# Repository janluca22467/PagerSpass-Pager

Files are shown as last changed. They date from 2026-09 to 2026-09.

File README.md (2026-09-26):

# PagerSpass Pager

Ein echter kleiner Funkmelder zum Selberbauen für **PagerSpass**. Optisch angelehnt an den Swissphone s.QUAD X35.

Du bist in einer Runde am PC, es kommt ein Alarm – und der Melder auf dem Tisch piept, die rote LED blinkt und auf dem Display steht die Meldung. Genau wie im Spiel, nur in echt.

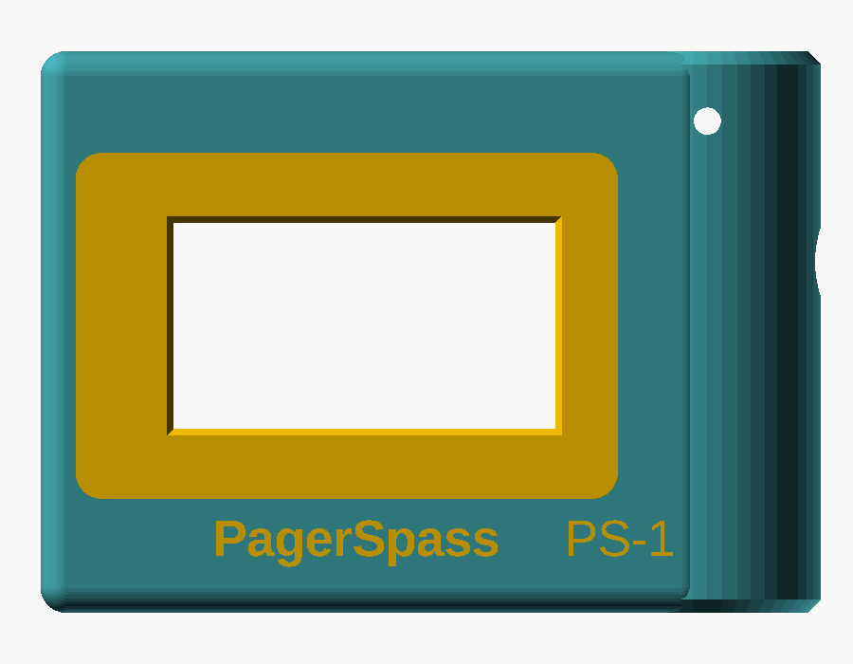
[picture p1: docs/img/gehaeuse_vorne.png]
Gehäuse


## Was kann er?

- Alarmierung mit Ton, roter LED und Anzeige wie im Spiel (Datum, Uhrzeit, Adresse, Text)
- Quittieren per Tastendruck – im Spiel ist der Alarm dann auch quittiert
- Anmeldung mit dem normalen PagerSpass Konto, kein Premium nötig
- Nachrichtenspeicher (die letzten 20)
- Melder-Menü: Lautstärke, Alarmton, Helligkeit, Stumm, Info …
- Einrichtung komplett über das Handy, kein Programmieren nötig
- Akku mit USB-C Laden

## Einrichtung in Kurz

1. Einschalten → „Willkommen zu PagerSpass Pager“
2. Mit dem Handy ins WLAN **Pager-XXXX** gehen, die Einrichtungsseite geht von selbst auf
3. Eigenes WLAN eintragen
4. PagerSpass Benutzername + Passwort eintragen (wie im Spiel)
5. Fertig – der Pager wartet jetzt auf eine Runde

## Teile

WeMos D1 Mini (ESP8266), 1.9" ST7789 Display (170x320), 4 Taster, Mini-Lautsprecher, rote LED, LiPo + TP4056. Zusammen ca. **15–20 €**. Genaue Liste: [docs/TEILELISTE.md](docs/TEILELISTE.md)

## Ordner

| Ordner | Inhalt |
|---|---|
| `firmware/` | Code für den D1 Mini (PlatformIO), dazu ein Simulator-Build |
| `case/` | Gehäuse, OpenSCAD-Datei + fertige STL |
| `hardware/` | Schaltplan |
| `tools/testserver/` | Testserver zum Ausprobieren ohne Spiel |

Braucht PagerSpass mit Pager-Anschluss (`/hub/pager`).
| `docs/` | Anleitung, Bedienung, Protokoll |

## Doku

- [Teileliste](docs/TEILELISTE.md)
- [Bauanleitung](docs/BAUANLEITUNG.md)
- [Bedienung](docs/BEDIENUNG.md)
- [Protokoll (für Server/Spiel)](docs/PROTOKOLL.md)
- [Am Mac testen ohne Hardware (Simulator)](docs/SIMULATOR.md)

## Lizenz

MIT, siehe [LICENSE](LICENSE). Nachbauen, verändern, verbessern – gerne! Pull Requests sind willkommen.

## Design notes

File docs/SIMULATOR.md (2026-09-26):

# Pager am Mac testen (ohne Hardware)

Mit **Wokwi** läuft die echte Firmware im Simulator: Display, Tasten, LED und Piepser sind auf dem Bildschirm, WLAN geht auch.

Unterschiede zum echten Gerät:

- Wokwi kann keinen ESP8266, darum läuft der Simulator auf einem **ESP32**. Der Code ist derselbe, nur die Pins sind andere.
- Wokwi hat kein 1.9" ST7789, darum nimmt der Simulator ein ILI9341 und nutzt davon einen Streifen mit 320x170 Pixeln.

## Einmal einrichten

1. **VS Code** installieren: https://code.visualstudio.com
2. In VS Code bei Erweiterungen installieren:
   - **PlatformIO IDE**
   - **Wokwi Simulator**
3. `F1` → „Wokwi: Request a new License“ → im Browser bestätigen (für Hobby kostenlos)
4. **Python 3** ist auf dem Mac meistens schon da (`python3 --version` im Terminal). Für den Testserver:
   ```
   cd tools/testserver
   pip3 install -r requirements.txt
   ```

## Starten

1. In VS Code **nur den Ordner `firmware/`** öffnen (Datei → Ordner öffnen)
2. Unten in der blauen Leiste bei PlatformIO die Umgebung **`env:sim`** wählen und auf ✓ (Build) klicken
   – oder im Terminal: `pio run -e sim`
3. `diagram.json` öffnen → der Pager wird angezeigt
4. `F1` → **„Wokwi: Start Simulator“**

Der Pager startet, zeigt „Willkommen“ und verbindet sich automatisch mit dem Simulator-WLAN (`Wokwi-GUEST`). Die WLAN-Einrichtung wird im Simulator übersprungen.

## Testen mit dem Testserver (ohne Spiel)

1. Terminal auf dem Mac:
   ```
   cd tools/testserver
   python3 server.py
   ```
2. Im Browser **http://localhost:8180** öffnen → das ist die Einrichtungsseite vom simulierten Pager
3. Benutzername egal, Passwort `test` → „Anmelden“
   (Server ist im Simulator schon auf `http://host.wokwi.internal:8080` gestellt = dein Mac)
4. Im Terminal vom Testserver:
   ```
   /start Stade
   B3 Wohnhausbrand | Hauptstraße 5 | Rauch aus Dachstuhl
   ```
   → Pager piept, LED blinkt, Meldung erscheint

## Testen mit dem echten Spiel

Geht genauso, nur auf der Einrichtungsseite unter „Erweitert“ als Server `https://pagerspass.de` eintragen und mit dem normalen Konto anmelden. Dann im Spiel einer Runde als Fahrzeug beitreten und alarmieren lassen.

(Der Server muss dafür den Pager-Anschluss schon haben, also nach dem Deploy.)

## Tasten

Man kann die Knöpfe anklicken oder die Tastatur nehmen (vorher einmal ins Simulator-Fenster klicken):

| Taste | Knopf |
|---|---|
| Enter | OK |
| Pfeil hoch | HOCH |
| Pfeil runter | RUNTER |
| Esc | ZURÜCK |

## Log

Unten in VS Code im Terminal-Bereich zeigt Wokwi die Ausgabe vom Pager, z. B.:

```
[boot] PagerSpass Pager 1.0.0
[boot] Display gestartet
[wifi] verbinde mit Wokwi-GUEST
[wifi] verbunden, IP 10.13.37.2
[setup] warte auf Anmeldung, Einrichtungsseite ist offen
```

Wenn was nicht geht: diese Zeilen angucken, da steht wo es hängt.

## Probleme

| Problem | Lösung |
|---|---|
| „firmware.bin not found“ | Erst bauen mit `env:sim`, nicht `env:pager` |
| localhost:8180 geht nicht | Simulator läuft? Pager zeigt „PagerSpass verknüpfen“? Ein paar Sekunden warten |
| „Server nicht erreichbar“ beim Testserver | Läuft `python3 server.py`? Server muss `http://host.wokwi.internal:8080` sein |
| Display bleibt schwarz | Nach dem Ändern immer neu bauen (`env:sim`) und den Simulator neu starten. Im Log muss „Display gestartet“ stehen |
| Alles zurücksetzen | Menü → Werkseinstellungen, oder Simulator neu starten und HOCH+RUNTER halten |

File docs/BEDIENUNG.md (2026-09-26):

# Bedienung

## Tasten

```
   [ZURÜCK]  [ HOCH ]  [RUNTER]
 ┌──────────────────────────┬───┐
 │                          │ ● │  ← LED
 │        Display           │   │
 │                          │ ◉ │  ← OK (Seite)
 │                          │   │
 │ PagerSpass        PS-1   │   │
 └──────────────────────────┴───┘
```

| Taste | kurz | lang |
|---|---|---|
| OK (Seite) | Menü / auswählen / Alarm quittieren | in der Nachrichtenliste: alle löschen |
| HOCH / RUNTER | blättern | schnell blättern |
| ZURÜCK | zurück | – |

Wenn das Display aus ist, macht der erste Tastendruck nur das Licht an. Beim Alarm quittiert jede Taste sofort.

## Erster Start

1. **Willkommen** – Einschalten, das Logo kommt.
2. **WLAN** – Auf dem Display steht `Pager-XXXX`. Mit dem Handy in dieses WLAN gehen. Die Einrichtungsseite geht normalerweise von selbst auf, sonst im Browser `http://192.168.4.1` öffnen. WLAN auswählen, Passwort rein, „Verbinden“.
3. **PagerSpass verknüpfen** – Die Seite wechselt automatisch. Benutzername und Passwort von deinem PagerSpass Konto eingeben, „Anmelden“. Wer Zwei-Faktor an hat, bekommt danach noch den Code abgefragt.
4. **Fertig** – Der Pager zeigt die Uhr und „Warte auf Runde…“.

Das Passwort wird nicht im Pager gespeichert, nur der Anmelde-Token vom Server. Wenn du dein Passwort änderst, will der Pager neu angemeldet werden.

## Startbildschirm

- oben: WLAN-Empfang und Akku
- Mitte: Uhrzeit und Datum
- unten: Status
  - „Warte auf Runde…“ – verbunden, du bist in keiner Runde
  - „Lobby: Ort“ – du bist in einer Runde, die noch nicht gestartet ist
  - Funkrufname + „BETRIEBSBEREIT“ – Runde läuft, Alarme kommen an
  - „Keine Verbindung“ – Server nicht erreichbar, er versucht es alle paar Sekunden
  - „x neue Nachrichten“

## Alarm

Kommt ein Alarm:

- Alarmton (30 Sekunden lang), rote LED blinkt
- Display: Datum, Uhrzeit und Schleife oben im Balken, darunter Stichwort, Adresse, Meldebild, Einheiten – wie der Melder im Spiel
- Eine Taste drücken = **quittiert**. Ton und LED gehen aus, die Meldung verschwindet und der Pager geht zurück auf den Startbildschirm – wie ein echter Melder. Im Spiel ist der Alarm dann auch quittiert. Die Meldung bleibt unter Menü → Nachrichten gespeichert.
- Der Ton ist derselbe wie im Spiel, und dringende Alarme (Priorität 3) klingen schneller – auch wie im Spiel.

Bei langen Texten mit HOCH/RUNTER scrollen.

## Menü

OK auf dem Startbildschirm:

| Punkt | Was |
|---|---|
| Nachrichten | Die letzten 20 Alarme. OK öffnet, in der Nachricht OK = löschen |
| Lautstärke | Aus, 1–5 |
| Alarmton | Alle 50 Meldertöne aus dem Spiel (Zweiklang, Dreiklang, Sirene …), spielen beim Auswählen an |
| Helligkeit | 1–5 |
| Stumm | An/Aus – nur LED, kein Ton |
| Info | Gerät, Firmware, IP, WLAN, Akku … |
| WLAN ändern | WLAN löschen, startet wieder mit Schritt 2 |
| Konto trennen | Pager vom PagerSpass Konto lösen, startet mit Schritt 3 |
| Werkseinstellungen | alles löschen |

## Zurücksetzen ohne Menü

HOCH + RUNTER gedrückt halten, einschalten, 5 Sekunden halten.

## Laden

USB-C Buchse unten in der Mitte (die linke ist nur zum Flashen). Rote LED am Modul = lädt, blau/grün = voll. Laden geht auch wenn der Pager aus ist.

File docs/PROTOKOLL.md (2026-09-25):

# Protokoll

So redet der Pager mit PagerSpass. Standard-Server ist `https://pagerspass.de`, kann bei der Einrichtung unter „Erweitert“ geändert werden (z. B. `https://beta.pagerspass.de`).

## 1. Anmelden

Ganz normal mit dem PagerSpass Konto, derselbe Weg wie im Spiel:

```
POST /api/konto/anmelden
{ "benutzername": "jan", "passwort": "geheim" }
```

Antwort: das Konto mit `merkmal` (das ist der Token). Den speichert der Pager, das Passwort nicht.

Bei Zwei-Faktor kommt stattdessen `{"zweiFaktor":true,"anfrage":"…","ziel":"j***@…"}`. Die Einrichtungsseite fragt dann den Code ab:

```
POST /api/konto/anmelden/zweifaktor
{ "anfrage": "…", "code": "123456" }
```

Fehler kommen als `{"fehler":"…"}` und werden so auf der Einrichtungsseite angezeigt.

## 2. Verbindung

WebSocket auf

```
/hub/pager
Authorization: Bearer <merkmal>
```

Kein Premium, kein QR-Code nötig. Der Pager bekommt die Alarme vom eigenen Platz in der Runde, der PC spielt ganz normal weiter.

## Server → Pager

Runde (bei jeder Änderung, alle ~10 s geprüft):

```json
{ "t": "round", "state": "waiting" }
{ "t": "round", "state": "lobby",  "name": "Stade", "code": "ABC123", "funkrufname": null }
{ "t": "round", "state": "active", "name": "Stade", "code": "ABC123", "funkrufname": "Florian Stade 1/46-1" }
```

Alarm – genau der Alarm vom Melder im Spiel:

```json
{
  "t": "alarm",
  "alarm": {
    "incidentId": "e4c82be9",
    "einsatznummer": "E-0002",
    "schleife": "FW Stade",
    "stichwort": "B3",
    "stichwortText": "Wohnhausbrand",
    "meldebild": "Rauch aus Dachstuhl",
    "adresse": "Hauptstraße 5",
    "ortsteil": null,
    "prioritaet": 3,
    "zeit": "2026-09-25T18:30:00+00:00",
    "einheiten": ["HLF 1/46-1", "DLK 1/33-1"],
    "zusatztext": null,
    "funkgruppe": "3301 Kreis West"
  }
}
```

Der Pager baut daraus dieselben Zeilen wie der DME im Spiel:

```
B3 Wohnhausbrand
Hauptstraße 5
Rauch aus Dachstuhl
GRUPPE 3301 Kreis West
EINH: HLF 1/46-1, DLK 1/33-1
```

Oben im Balken stehen Zeit und Schleife.

Merkmal ungültig (z. B. Passwort geändert):

```json
{ "t": "unlinked" }
```

→ Pager startet die Anmeldung neu.

## Pager → Server

Quittieren:

```json
{ "t": "ack" }
```

Das ist dasselbe wie „Quittieren“ im Spiel.

## Testserver

`tools/testserver/server.py` macht dasselbe ohne Spiel, zum Ausprobieren.

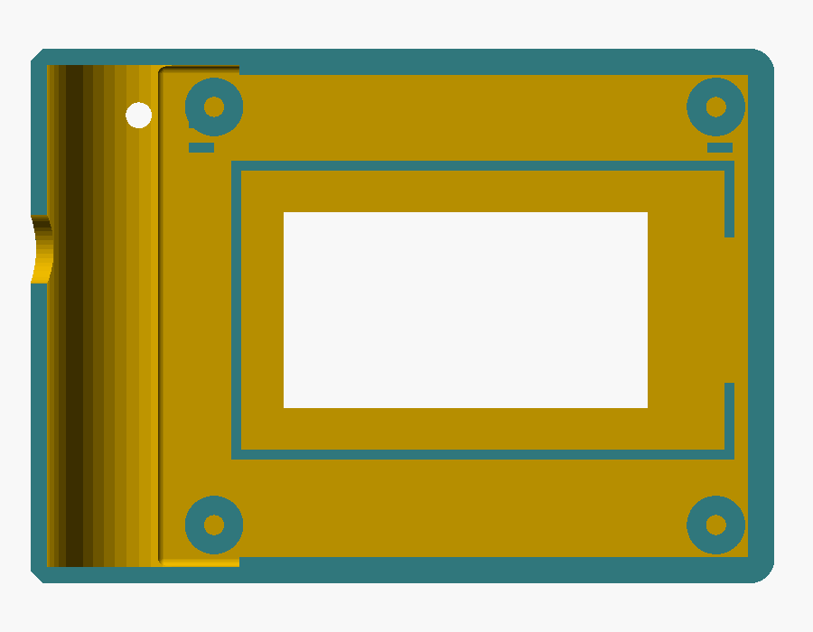
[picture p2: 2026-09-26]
docs/img/gehaeuse_vorne_innen.png

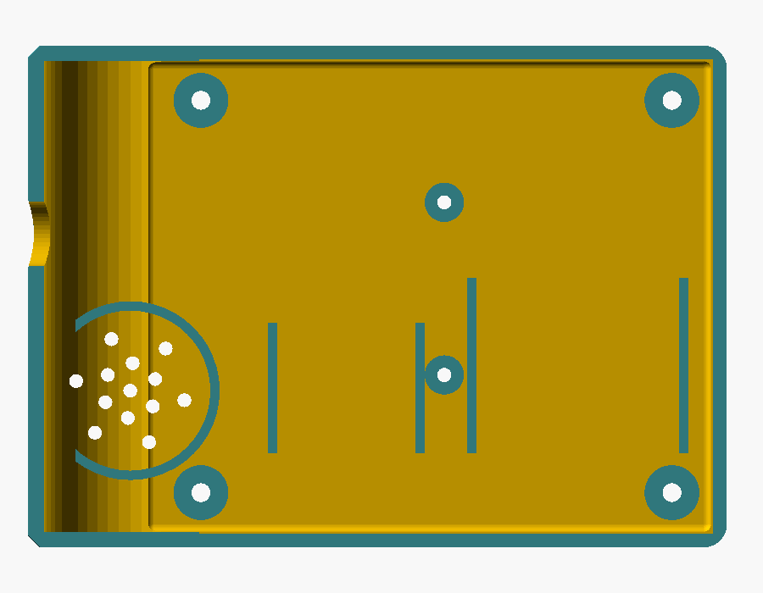
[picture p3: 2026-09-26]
docs/img/gehaeuse_hinten.png

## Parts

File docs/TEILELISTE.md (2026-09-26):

# Teileliste

| Nr | Teil | Anzahl | ca. Preis | Hinweis |
|---|---|---|---|---|
| U1 | **WeMos D1 Mini V4.0.0 Type-C** (ESP8266, ESP-12F, CH340G) | 1 | 3–4 € | das „Gehirn“ |
| U2 | **1.9" TFT IPS, ST7789, 170x320, SPI** | 1 | 4–5 € | 8 Pins: GND VCC SCL SDA RES DC CS BLK |
| U3 | TP4056 Lademodul USB-C **mit Schutzschaltung** | 1 | 0,50 € | die Version mit OUT+/OUT- (6 Lötpunkte) |
| BT1 | LiPo Akku 503450, 3.7 V, 1000 mAh | 1 | 4 € | 50 x 34 x 5 mm, mit Schutzplatine und Kabel |
| LS1 | Mini Lautsprecher 8 Ω, 0,5 W, Ø 20 mm | 1 | 1 € | im Gehäuse ist Platz für Ø 20 mm |
| Q1 | NPN Transistor S8050 (oder 2N2222 / BC337) | 1 | – | |
| D1 | Diode 1N4148 | 1 | – | |
| D2 | LED rot 3 mm | 1 | – | |
| R1 | Widerstand 1 kΩ | 1 | – | |
| R2 | Widerstand 10 Ω | 1 | – | |
| R3 | Widerstand 330 Ω | 1 | – | |
| R4 | Widerstand 100 kΩ | 1 | – | Akku messen |
| S1–S4 | **Taster 6x6x4.3 mm** (4 Beinchen) | 4 | – | |
| SW1 | Schiebeschalter SS12D00 | 1 | – | |
| – | Lochrasterplatine 5 x 7 cm | 1 | – | für die Tasten oben, siehe Bauanleitung |
| – | Schrauben M2 x 10 (selbstschneidend) | 4 | – | Gehäuse |
| – | Schrauben M2 x 6 Senkkopf | 2 | – | Gürtelclip |
| – | Litze 0,14 mm², Schrumpfschlauch, Heißkleber, doppelseitiges Klebeband | | | |

Widerstände, Diode, Transistor und LED gibt es am günstigsten als Sortiment.

**Summe:** ca. 15–20 € (ohne Filament)

## Worauf man beim Kaufen achten sollte

- **D1 Mini:** genau der ESP8266 (ESP-12F). Nicht „D1 Mini ESP32“, das ist ein anderes Board mit anderen Pins.
- **Display:** 1.9 Zoll mit **170x320** und **ST7789**. Es gibt auch 1.9" mit anderer Auflösung, die gehen nicht ohne Änderung.
- **TP4056:** die Version **mit** Schutz (hat OUT+ und OUT-). Die ohne Schutz hat nur B+/B-.
- **Akku:** mit Schutzplatine, Kabel dran. Maße ungefähr 50 x 34 x 5 mm, sonst passt er nicht ins Gehäuse.
- **Taster:** 6x6 mm, **4,3 mm hoch**. Die Tastenkappen im Gehäuse sind genau darauf abgestimmt.

## Werkzeug

- Lötkolben
- 3D-Drucker (PLA oder PETG)
- Heißklebepistole
- Cutter oder feine Säge (für die Lochrasterplatine)
- kleiner Kreuzschlitz
- Mac/PC mit VS Code + PlatformIO zum Flashen

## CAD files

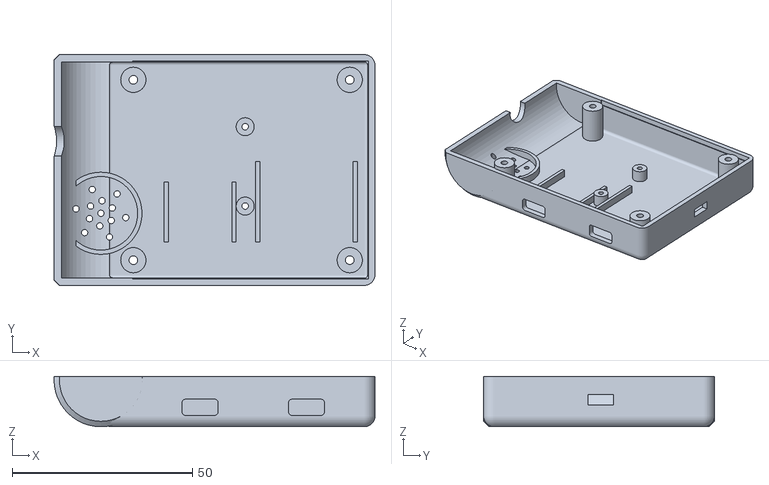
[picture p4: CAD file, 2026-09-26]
case/stl/pager_back.stl
89.0 x 64.0 x 14.0

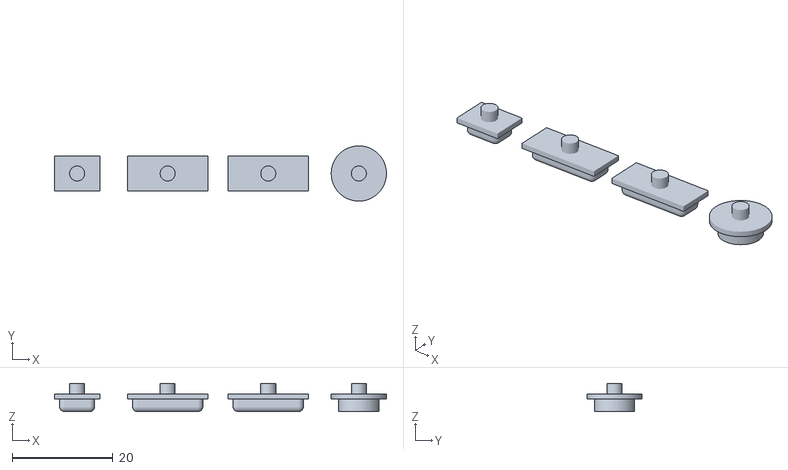
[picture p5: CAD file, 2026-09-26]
case/stl/pager_buttons.stl
66.0 x 11.0 x 5.60

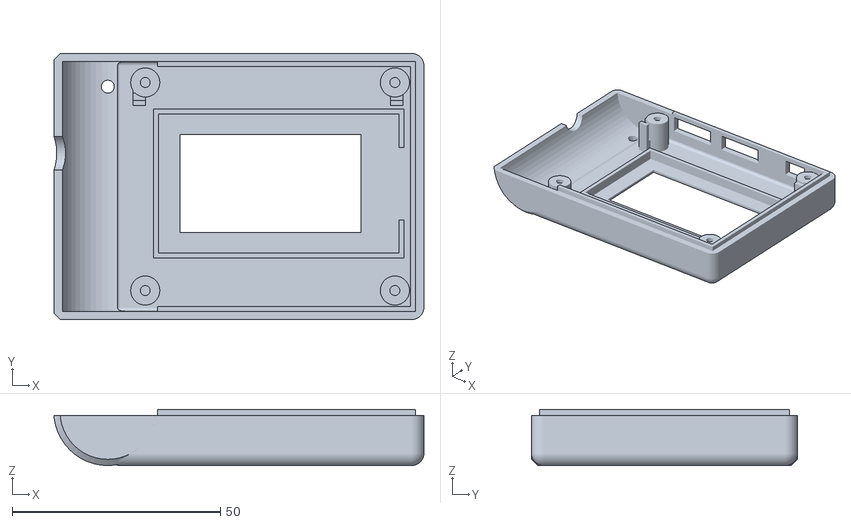
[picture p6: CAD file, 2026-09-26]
case/stl/pager_front.stl
88.9 x 64.0 x 13.5

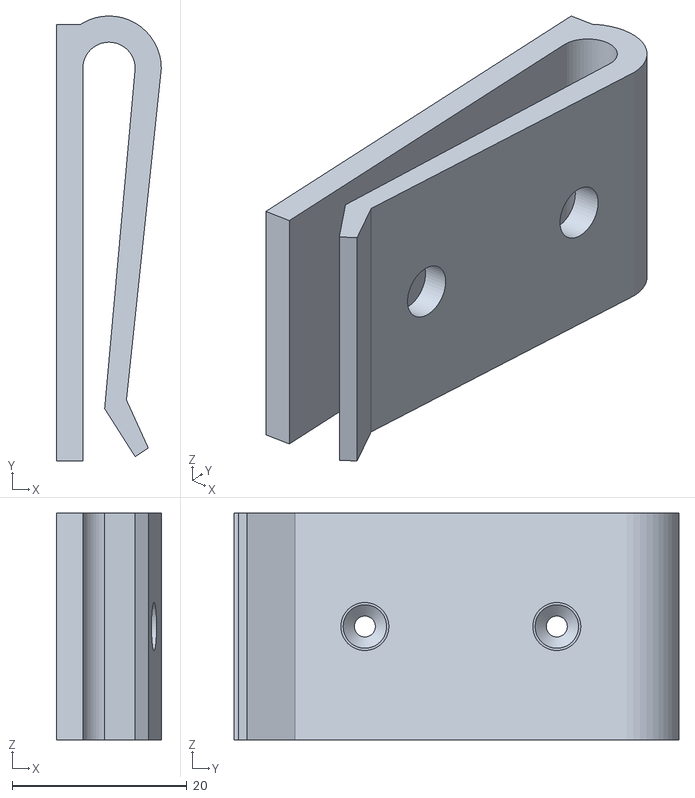
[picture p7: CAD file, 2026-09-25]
case/stl/pager_clip.stl
12.0 x 51.0 x 26.0

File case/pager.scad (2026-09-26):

// PagerSpass Pager - Gehaeuse
// part = "front" | "back" | "buttons" | "clip" | "all"
part = "all";

$fn = 48;

body_w = 76;
body_h = 64;
depth = 26;
split = 12;
wall = 2;
r_edge = 3;

roll_r = 13;
roll_x = body_w;

// 1.9" ST7789 170x320 - vor dem Drucken am eigenen Modul nachmessen!
disp_pcb = [57.8, 33.4];
disp_pos = [6, 16];
disp_win = [43.5, 23.5];
disp_win_off = [2, 0];

top_btns = [[16, 7], [38, 14], [57, 14]];
btn_z = 9;
btn_depth = 5;
// Taster 6x6x4.3: Platine im Halter, Stoessel bis kurz vor den Knopf
btn_stem = 2.2;
side_btn_y = 40;
side_btn_d = 8;

led_pos = [76, 56];
led_d = 3.1;

spk_pos = [76, 20];
spk_d = 20.4;

// WeMos D1 Mini (25.6 x 34.2) und TP4056 (17.4 x 28.5), USB-C jeweils unten
d1_size = [25.8, 34.4];
tp_size = [17.6, 28.7];
usb_esp_x = 19;
usb_tp_x = 48.5;
usb_z = 20.6;

screws = [[7, 7], [7, 57], [67, 7], [67, 57]];
clip_holes = [[36, 22], [36, 44]];

module rbox(size, r) {
  hull() for (x = [r, size[0] - r], y = [r, size[1] - r], z = [r, size[2] - r])
    translate([x, y, z]) sphere(r);
}

module roller(r, extra = 0) {
  translate([roll_x, -extra, split + 1]) rotate([-90, 0, 0])
    hull() {
      translate([0, 0, 1.5]) cylinder(r = r, h = body_h + 2 * extra - 3);
      cylinder(r = r - 1.5, h = body_h + 2 * extra);
    }
}

module outer() {
  rbox([body_w, body_h, depth], r_edge);
  roller(roll_r);
}

module inner() {
  translate([wall, wall, wall]) rbox([body_w - 2 * wall, body_h - 2 * wall, depth - 2 * wall], 1);
  intersection() {
    roller(roll_r - wall);
    translate([0, wall, 0]) cube([200, body_h - 2 * wall, 100]);
  }
}

module cutouts() {
  // Display-Fenster mit Fase
  wx = disp_pos[0] + disp_pcb[0] / 2 - disp_win[0] / 2 + disp_win_off[0];
  wy = disp_pos[1] + disp_pcb[1] / 2 - disp_win[1] / 2 + disp_win_off[1];
  translate([wx, wy, -1]) cube([disp_win[0], disp_win[1], 5]);
  hull() {
    translate([wx, wy, 1.2]) cube([disp_win[0], disp_win[1], 0.01]);
    translate([wx - 1.5, wy - 1.5, -0.01]) cube([disp_win[0] + 3, disp_win[1] + 3, 0.01]);
  }

  // Rahmen-Vertiefung wie beim Original
  translate([disp_pos[0] - 2, disp_pos[1] - 3, -0.01]) linear_extrude(0.6)
    offset(r = 3) offset(delta = -3) square([disp_pcb[0] + 4, disp_pcb[1] + 6]);

  translate([36, 6.5, -0.01]) linear_extrude(0.6)
    text("PagerSpass", size = 4.2, font = "Liberation Sans:style=Bold", halign = "center");
  translate([66, 6.5, -0.01]) linear_extrude(0.6)
    text("PS-1", size = 4.2, font = "Liberation Sans", halign = "center");

  for (b = top_btns)
    translate([b[0] - (b[1] + 0.6) / 2, body_h - wall - 1, btn_z - (btn_depth + 0.6) / 2])
      cube([b[1] + 0.6, wall + 2, btn_depth + 0.6]);

  translate([roll_x + roll_r - wall - 1, side_btn_y, split + 1]) rotate([0, 90, 0])
    cylinder(d = side_btn_d + 0.4, h = wall + 3);

  translate([led_pos[0], led_pos[1], -1]) cylinder(d = led_d, h = 6);

  for (a = [0 : 60 : 359]) for (r = [0, 3.5, 7])
    if (r > 0 || a == 0)
      translate([spk_pos[0] + r * cos(a + r * 10), spk_pos[1] + r * sin(a + r * 10), depth - 6])
        cylinder(d = 1.8, h = 8, $fn = 12);

  for (x = [usb_esp_x, usb_tp_x])
    translate([x - 5, -1, usb_z - 2.25]) rbox([10, wall + 2, 4.5], 1);

  translate([-1, 29, 17]) cube([wall + 2, 7, 3]);

  for (s = screws) {
    translate([s[0], s[1], 16]) cylinder(d = 4.6, h = 20);
    translate([s[0], s[1], 5]) cylinder(d = 2.4, h = 20);
  }

  for (c = clip_holes) {
    translate([c[0], c[1], depth - 7]) cylinder(d = 1.8, h = 8);
  }
}

module inner_parts() {
  for (s = screws) translate([s[0], s[1], 1]) cylinder(d = 7, h = depth - 2);

  // Displayrahmen
  translate([0, 0, wall - 0.01]) difference() {
    translate(disp_pos - [1.2, 1.2]) cube([disp_pcb[0] + 2.4, disp_pcb[1] + 2.4, 3]);
    translate(disp_pos) cube([disp_pcb[0], disp_pcb[1], 4]);
    translate(disp_pos + [-2, 8]) cube([4, disp_pcb[1] - 16, 4]);
  }

  // Halter fuer Tastenplatine
  for (x = [5, 67]) translate([x, body_h - 12.5, wall - 0.01]) difference() {
    cube([3, 4, split - wall + 0.01]);
    translate([-1, 1.2, 4]) cube([5, 1.8, 20]);
  }

  translate([spk_pos[0], spk_pos[1], depth - wall - 2.5]) difference() {
    cylinder(d = spk_d + 2.4, h = 2.51);
    translate([0, 0, -1]) cylinder(d = spk_d, h = 5);
  }

  for (c = clip_holes) translate([c[0], c[1], depth - wall - 4]) cylinder(d = 5, h = 4.01);

  // Platinenhalter hinten (ESP32-C3 + TP4056)
  for (b = [[usb_esp_x, d1_size[0], d1_size[1]], [usb_tp_x, tp_size[0], tp_size[1]]])
    for (sx = [-1, 1])
      translate([b[0] + sx * (b[1] / 2 + 0.6) - 0.6, wall + 10, depth - wall - 2.5])
        cube([1.2, b[2] - 12, 2.51]);
}

module shell() {
  difference() {
    union() {
      difference() {
        outer();
        inner();
      }
      intersection() {
        inner_parts();
        outer();
      }
    }
    cutouts();
  }
}

module front() {
  intersection() {
    shell();
    translate([-10, -10, -1]) cube([150, 100, split + 1]);
  }
  // Lippe zum Zentrieren
  translate([0, 0, split - 0.01]) intersection() {
    difference() {
      translate([wall, wall, 0]) cube([body_w - 2 * wall, body_h - 2 * wall, 1.5]);
      translate([wall + 1.2, wall + 1.2, -1]) cube([body_w - 2 * wall - 2.4, body_h - 2 * wall - 2.4, 4]);
      translate([body_w - 10, 0, -1]) cube([20, body_h, 4]);
    }
    translate([-1, -1, 0]) cube([body_w - 11, body_h + 2, 2]);
  }
}

module back() {
  difference() {
    intersection() {
      shell();
      translate([-10, -10, split]) cube([150, 100, 50]);
    }
    translate([wall - 0.25, wall - 0.25, split - 1]) difference() {
      cube([body_w - 2 * wall + 0.5, body_h - 2 * wall + 0.5, 2.8]);
      translate([1.7, 1.7, -1]) cube([body_w - 2 * wall - 2.9, body_h - 2 * wall - 2.9, 5]);
      translate([body_w - 10.5, -1, -1]) cube([20, body_h, 6]);
    }
  }
}

module btn_cap(w) {
  translate([-w / 2, -btn_depth / 2, 0]) rbox([w, btn_depth, 3.5], 1);
  translate([-(w + 2) / 2, -(btn_depth + 2) / 2, 2.5]) cube([w + 2, btn_depth + 2, 1]);
  translate([0, 0, 3.4]) cylinder(d = 3, h = btn_stem);
}

module side_cap() {
  cylinder(d = side_btn_d, h = 3.5);
  translate([0, 0, 2.5]) cylinder(d = side_btn_d + 3, h = 1);
  translate([0, 0, 3.4]) cylinder(d = 3, h = btn_stem);
}

module buttons() {
  translate([6, 0, 0]) btn_cap(7);
  translate([24, 0, 0]) btn_cap(14);
  translate([44, 0, 0]) btn_cap(14);
  translate([62, 0, 0]) side_cap();
}

module clip_profile() {
  square([3, 50]);
  translate([6, 45]) difference() {
    circle(r = 6);
    circle(r = 3);
    translate([-7, -7]) square([14, 7]);
  }
  polygon([[9, 45], [12, 45], [8, 7], [5.5, 6]]);
  polygon([[5.5, 6], [8, 7], [10.5, 1.5], [9, 0.5]]);
}

module clip_part() {
  w = 26;
  hole_dy = clip_holes[1][1] - clip_holes[0][1];
  difference() {
    linear_extrude(w) clip_profile();
    for (y = [15, 15 + hole_dy]) translate([-1, y, w / 2]) rotate([0, 90, 0]) {
      cylinder(d = 2.4, h = 5);
      translate([0, 0, 2.6]) cylinder(d1 = 2.4, d2 = 5, h = 1.41);
      translate([0, 0, 5]) cylinder(d = 5.5, h = 15);
    }
  }
}

// Modell ist von hinten gesehen aufgebaut, darum am Ende spiegeln
if (part == "front") mirror([1, 0, 0]) front();
else if (part == "back") mirror([1, 0, 0]) translate([0, 0, depth]) mirror([0, 0, 1]) back();
else if (part == "buttons") buttons();
else if (part == "clip") clip_part();
else mirror([1, 0, 0]) {
  color("#333") front();
  color("#444") translate([0, 0, 15]) back();
}

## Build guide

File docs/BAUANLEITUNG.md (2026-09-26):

# Bauanleitung

Dauer: ungefähr ein Nachmittag (+ Druckzeit).

## 1. Gehäuse drucken

Die fertigen Dateien liegen in `case/stl/`:

| Datei | Was | Ausrichtung |
|---|---|---|
| `pager_front.stl` | Vorderteil mit Display-Fenster | Vorderseite aufs Bett (liegt schon richtig) |
| `pager_back.stl` | Rückteil mit Lautsprecher-Löchern | Rückseite aufs Bett (liegt schon richtig) |
| `pager_buttons.stl` | 3 Tasten oben + 1 Seitentaste | liegt richtig |
| `pager_clip.stl` | Gürtelclip | liegt richtig, **nicht drehen** (sonst bricht er) |

Einstellungen die bei mir gut gingen:

- PLA oder PETG (Clip besser PETG)
- 0,2 mm Schichthöhe, 3 Wände, 20 % Infill
- Stützstrukturen: nur „nur vom Druckbett“ für Vorder- und Rückteil (USB-Löcher, Seitentaste)
- Schwarz oder Dunkelgrau sieht am meisten nach echtem Melder aus

Wer was ändern will (anderes Display, dickerer Akku …): `case/pager.scad` in OpenSCAD öffnen, oben stehen alle Maße. Danach z. B.

```
openscad -D 'part="front"' -o stl/pager_front.stl pager.scad
```

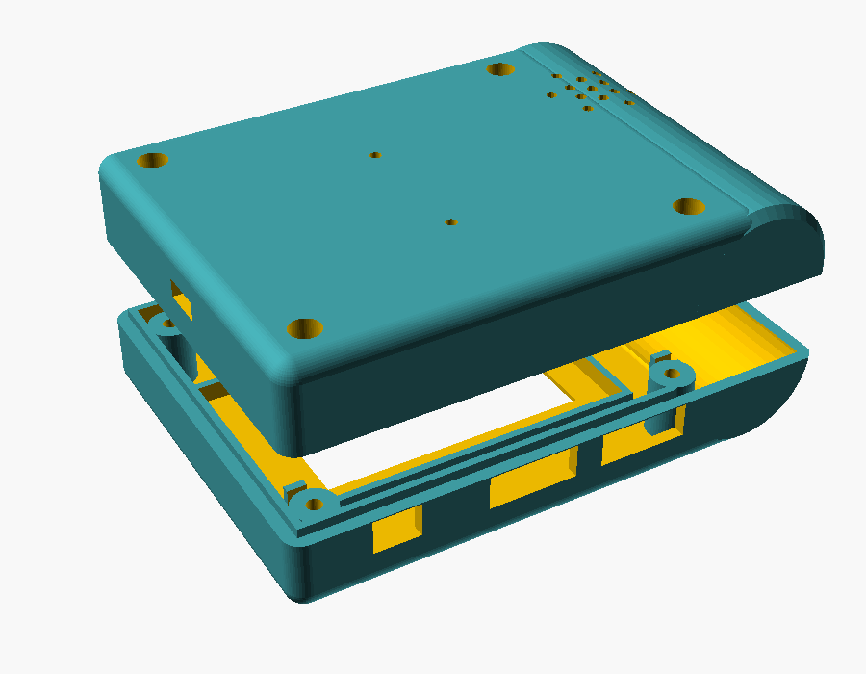
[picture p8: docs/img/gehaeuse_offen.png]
offen


> **Wichtig:** Die 1.9" Display-Module sind nicht alle gleich groß. Miss deins nach (Platine und sichtbare Fläche) und trag die Maße in `disp_pcb`, `disp_win` und `disp_win_off` ein, bevor du druckst. Eingestellt sind 57,8 x 33,4 mm Platine und 43,5 x 23,5 mm Fenster.

## 2. Schaltplan

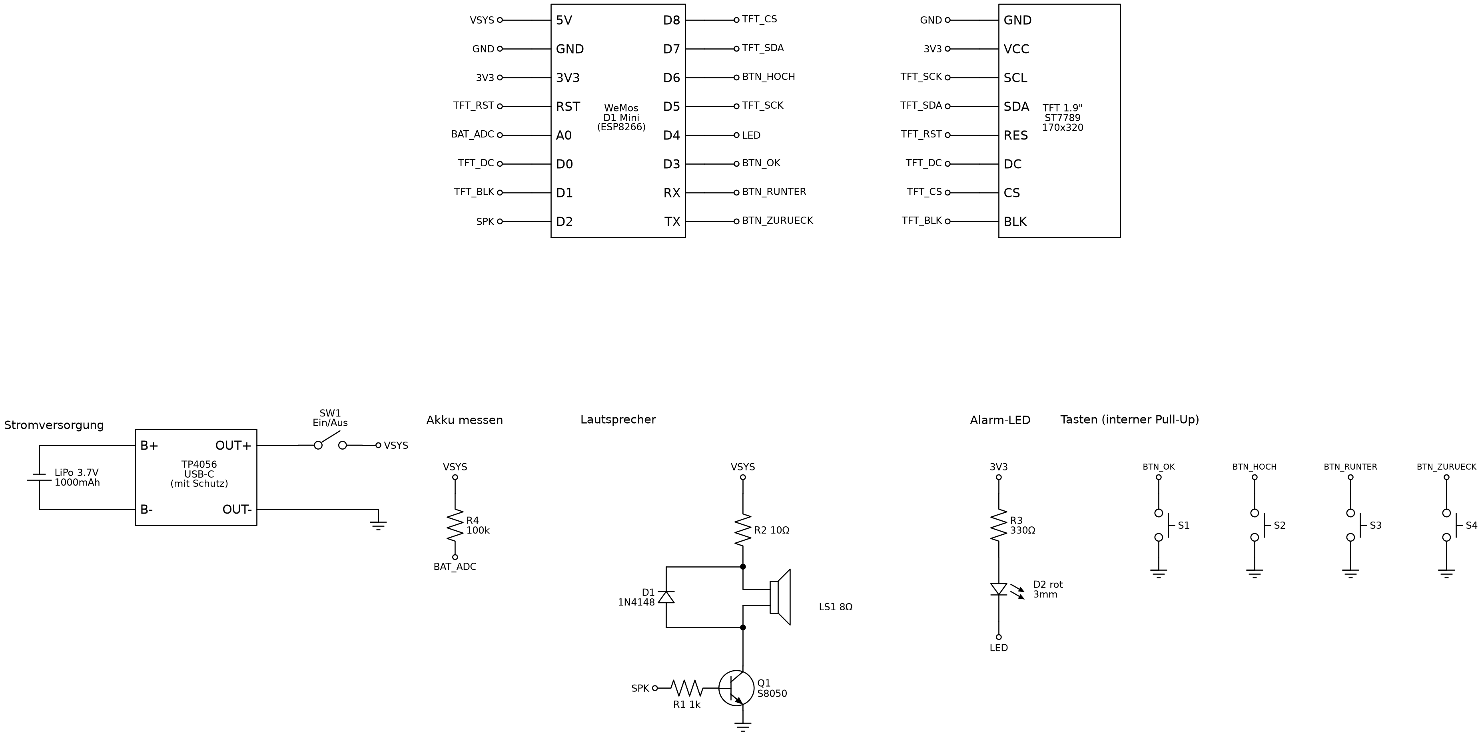
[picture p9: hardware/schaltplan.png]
Schaltplan


### Verdrahtung

| D1 Mini | geht an |
|---|---|
| 5V | VSYS (Schiebeschalter → TP4056 OUT+) |
| GND | GND von allem |
| 3V3 | Display VCC, LED (über R3) |
| RST | Display RES |
| A0 | über R4 100 kΩ an VSYS (Akku messen) |
| D0 | Display DC |
| D1 | Display BLK |
| D2 | R1 1 kΩ → Basis Q1 (Lautsprecher) |
| D3 | Taster OK (Seite) → GND |
| D4 | LED: 3V3 → R3 330 Ω → LED → D4 |
| D5 | Display SCL |
| D6 | Taster HOCH → GND |
| D7 | Display SDA |
| D8 | Display CS |
| RX | Taster RUNTER → GND |
| TX | Taster ZURÜCK → GND |

Jeder Pin vom D1 Mini ist belegt, auch RX und TX. Darum gibt der Pager am echten Gerät nichts über USB aus (im Simulator schon).

Die Taster brauchen keine Widerstände, das macht der ESP intern (Pull-Up).

Die LED hängt „andersrum“ (von 3V3 zum Pin), weil D4 beim Starten HIGH sein muss. Die kleine blaue LED auf dem D1 Mini blinkt deshalb mit, das ist normal.

Lautsprecher: VSYS → R2 10 Ω → Lautsprecher → Kollektor Q1, Emitter an GND. Die 1N4148 parallel zum Lautsprecher, Strich (Kathode) Richtung VSYS.

## 3. Löten

Reihenfolge wie ich es gemacht habe:

1. **Tastenplatine:** Von der 5x7 cm Lochrasterplatine an der langen Seite einen Streifen abschneiden, **4 Löcher breit** (ca. 10 mm). Mit dem Cutter mehrmals entlang einer Lochreihe ritzen und abbrechen, Kante kurz anschleifen. Dann auf **60 mm** Länge kürzen. Drei Taster drauf, Mitte von links (von vorne gesehen): 16 mm, 38 mm, 57 mm. Das sind ZURÜCK, HOCH, RUNTER. Eine gemeinsame GND-Leitung, jeder Taster ein eigenes Kabel.
2. **Display:** 8 Kabel an das Display löten (ca. 8 cm lang). Keine Stiftleiste, die ist zu hoch!
3. **Lautsprecher-Teil:** Q1, R1, R2 und D1 fliegend oder auf einem kleinen Rest von der Lochrasterplatine, gut mit Schrumpfschlauch isolieren.
4. **LED:** R3 direkt an das Beinchen löten, Schrumpfschlauch drüber.
5. **Seitentaste (OK):** einzelner Taster, zwei Kabel.
6. **Akku messen:** R4 zwischen VSYS und A0.
7. **Strom:** Akku an B+/B- vom TP4056. OUT+ an den Schiebeschalter, vom Schalter an 5V vom D1 Mini. OUT- an GND.

> Akku-Kabel **nie** kurzschließen. Erst alles andere fertig machen, Akku zum Schluss anlöten.

> **Wichtig:** Wenn der D1 Mini per USB am Rechner hängt, muss der Schiebeschalter auf **AUS** stehen. Sonst drückt der USB 5 V direkt in den Akku.

## 4. Firmware flashen

1. [VS Code](https://code.visualstudio.com/) + PlatformIO Erweiterung installieren
2. Ordner `firmware/` öffnen
3. **Schiebeschalter auf AUS**, dann den D1 Mini per USB-C an den Rechner
4. Unten die Umgebung **`env:pager`** wählen und auf den Pfeil (Upload) klicken

Wird der D1 Mini nicht erkannt: Der CH340 Treiber fehlt. Beim Mac ist er ab macOS 11 dabei, sonst von der Seite vom Hersteller (WCH) laden. Und ein USB-Kabel nehmen, das auch Daten kann (manche können nur Laden).

Über die Konsole geht es auch:

```
cd firmware
pio run -e pager -t upload
```

> Beim Einschalten **nicht OK gedrückt halten**. OK hängt an D3, und damit startet der D1 Mini im Flash-Modus statt normal.

## 5. Zusammenbauen

1. Display ins Vorderteil legen, Glas Richtung Fenster. Es sitzt im Rahmen, mit ein paar Punkten Heißkleber am Rand fixieren.
2. Tastenkappen von innen in die Löcher oben stecken, dann die Tastenplatine in die zwei Halter schieben (bisschen Heißkleber).
3. LED von innen in das kleine Loch rechts oben (Walze) drücken, Kleber drauf.
4. Seitentaste: Kappe in die halbe Öffnung an der Walze legen, Taster dahinter mit Heißkleber fest.
5. Akku mit doppelseitigem Klebeband hinter das Display kleben.
6. Im Rückteil: Lautsprecher in den Ring kleben, D1 Mini und TP4056 zwischen die Führungen legen, USB-Buchsen in die Öffnungen unten. Mit Heißkleber fixieren.
7. Schiebeschalter in den Schlitz an der linken Seite kleben.
8. Kabel ordentlich legen, zuklappen, 4 Schrauben M2 x 10 von hinten.
9. Gürtelclip mit 2 Senkkopfschrauben hinten dran. Durch die Löcher im Clip kommt man mit dem Schraubenzieher an die Schrauben.

## 6. Erster Test ohne Spiel

Im Ordner `tools/testserver` ist ein kleiner Server der so tut als wäre er PagerSpass:

```
cd tools/testserver
pip install -r requirements.txt
python server.py
```

Bei der Einrichtung unter „Erweitert“ als Server `http://<IP von deinem PC>:8080` eintragen, Benutzername egal, Passwort `test`.

Dann im Terminal:

```
/start Stade
B3 Wohnhausbrand | Hauptstraße 5 | Rauch aus Dachstuhl
```

→ Pager sollte piepen. Mehr Befehle stehen beim Start im Terminal.

## Probleme

| Problem | Lösung |
|---|---|
| Display bleibt weiß/schwarz | Kabel SCL/SDA/DC/CS prüfen, BLK an D1? RES am RST vom D1 Mini? |
| Farben komisch/invertiert | Bei manchen Displays in `display.cpp` nach `tft.init` ein `tft.invertDisplay(false);` einfügen |
| Kein Ton | Q1 richtig rum? (E-B-C) R2 dran? |
| Pager startet immer neu | Akku leer oder Schalter wackelt |
| Pager startet nicht, Display bleibt dunkel | OK beim Einschalten gedrückt? Dann startet er im Flash-Modus |
| Akku zeigt „USB“ | R4 nicht angeschlossen |
| WLAN „Pager-XXXX“ taucht nicht auf | Alles zurücksetzen: HOCH + RUNTER beim Einschalten 5 s halten |

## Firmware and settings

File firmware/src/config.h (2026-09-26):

#pragma once

#ifdef ESP8266
// WeMos D1 Mini (ESP8266). Jeder Pin ist belegt, auch RX/TX (darum kein Serial).
#define PIN_SCK      14  // D5
#define PIN_MOSI     13  // D7
#define PIN_TFT_CS   15  // D8
#define PIN_TFT_DC   16  // D0
#define PIN_TFT_RST  -1  // RES haengt am RST vom D1 Mini
#define PIN_TFT_BL   5   // D1
#define PIN_BUZZER   4   // D2
#define PIN_BTN_OK   0   // D3
#define PIN_LED      2   // D4, LED gegen 3V3 -> LOW = an
#define PIN_BTN_UP   12  // D6
#define PIN_BTN_DOWN 3   // RX
#define PIN_BTN_BACK 1   // TX
#define PIN_BAT      A0
#define LED_ON LOW
#else
// ESP32 fuer den Simulator
#define PIN_SCK      18
#define PIN_MOSI     23
#define PIN_TFT_CS   5
#define PIN_TFT_DC   16
#define PIN_TFT_RST  17
#define PIN_TFT_BL   4
#define PIN_BTN_OK   27
#define PIN_BTN_UP   25
#define PIN_BTN_DOWN 26
#define PIN_BTN_BACK 32
#define PIN_BUZZER   13
#define PIN_LED      22
#define PIN_BAT      35
#define LED_ON HIGH
#endif

// 1.9" ST7789, 170x320 quer
#define SCREEN_W 320
#define SCREEN_H 170

#ifdef SIM
#define DEFAULT_SERVER "http://host.wokwi.internal:8080"
#else
#define DEFAULT_SERVER "https://pagerspass.de"
#endif

#define TZ_INFO "CET-1CEST,M3.5.0,M10.5.0/3"
#define MAX_MSGS 10
#define MSG_LEN 280
#define ALARM_SECONDS 30
#define LIGHT_SECONDS 15

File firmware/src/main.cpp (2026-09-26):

#include <Arduino.h>
#include <time.h>
#include "config.h"
#include "store.h"
#include "plattform.h"
#include "display.h"
#include "buttons.h"
#include "sound.h"
#include "portal.h"
#include "pagerspass.h"
#include "ui.h"

enum Mode { M_SETUP_WIFI, M_SETUP_ACCOUNT, M_RUN };
enum Screen { S_HOME, S_MENU, S_LIST, S_MSG, S_ALARM, S_VALUE, S_CONFIRM, S_INFO };
enum Menu { MN_MSGS, MN_VOL, MN_TONE, MN_LIGHT, MN_MUTE, MN_INFO, MN_WIFI, MN_UNLINK, MN_RESET, MN_COUNT };
enum Confirm { C_DELETE, C_DELETE_ALL, C_WIFI, C_UNLINK, C_RESET };

static Mode mode;
static Screen screen = S_HOME;
static bool dirty = true;

static int menuSel = 0, listSel = 0, msgIdx = 0, msgScroll = 0, msgLines = 0;
static int editVal = 0;
static int infoScroll = 0;
static Menu editing;
static Confirm confirming;
static Screen confirmBack;

static uint32_t alarmStart = 0;
static uint32_t lastInput = 0;
static bool lightOn = true;
static uint32_t lastTick = 0;
static uint32_t wifiTryStart = 0, doneAt = 0;
static String pendingSsid, pendingPass;
static String pendingServer, pendingRequest;

static int readBattery() {
  uint32_t mv = 0;
#ifdef ESP8266
  // A0 vom D1 Mini hat schon 220k/100k drauf, mit den 100k extra sind 4.2V am Akku = 1023
  for (int i = 0; i < 8; i++) mv += analogRead(PIN_BAT);
  mv = mv / 8 * 4200 / 1023;
#else
  for (int i = 0; i < 8; i++) mv += analogReadMilliVolts(PIN_BAT);
  mv = mv / 8 * 2;
#endif
  if (mv < 2500) return -1;
  return constrain(map(mv, 3300, 4150, 0, 100), 0, 100);
}

static void wake() {
  lastInput = millis();
  if (!lightOn) {
    lightOn = true;
    backlight(cfg.light);
  }
}

static void go(Screen s) {
  screen = s;
  dirty = true;
}

static void showSetupWifi() {
  if (setupState == SS_WIFI_FAIL)
    uiSetup("Einrichtung 1/2", "Verbindung fehlgeschlagen. Verbinde dich mit dem WLAN", apName(), "und versuche es nochmal.", setupError);
  else
    uiSetup("Einrichtung 1/2", "Willkommen! Verbinde dich mit dem WLAN", apName(), "Die Einrichtung öffnet sich dann von selbst.", "Falls nicht: http://192.168.4.1 öffnen");
}

static void showSetupAccount() {
#ifdef SIM
  String ip = "localhost:8180";
#else
  String ip = WiFi.localIP().toString();
#endif
  switch (setupState) {
    case SS_LINKING:
      uiSetup("Einrichtung 2/2", "Melde bei PagerSpass an...", "", "", "");
      break;
    case SS_LINK_FAIL:
      uiSetup("Einrichtung 2/2", "Anmeldung fehlgeschlagen:", "", setupError, "http://" + ip);
      break;
    case SS_CODE:
      uiSetup("Einrichtung 2/2", "Bestätigungscode", "", "Gib den Code aus der E-Mail im Browser ein.", "");
      break;
    case SS_DONE:
      uiSetup("Fertig", "Dein Pager ist verknüpft.", "Hallo " + cfg.user + "!", "", "");
      break;
    default:
      uiSetup("Einrichtung 2/2", "PagerSpass verknüpfen", "", "Gib jetzt im Browser deine PagerSpass Daten ein.", "Im Browser: http://" + ip);
  }
}

static void onAlarm(const Alarm &a) {
  Msg m = {};
  m.ts = a.ts ? a.ts : (uint32_t)time(nullptr);
  m.prio = a.prio;
  m.read = 0;
  strlcpy(m.head, a.head.c_str(), sizeof(m.head));
  strlcpy(m.text, a.text.c_str(), sizeof(m.text));
  addMsg(m);

  alarmStart = millis();
  msgIdx = 0;
  msgScroll = 0;
  playAlarm(cfg.tone, a.prio, true);
  ledBlink(true);
  lightOn = true;
  lastInput = millis();
  backlight(5);
  go(S_ALARM);
}

static void onRound(RoundState r, const String &name, const String &callsign) {
  bool started = r == R_ACTIVE && st.round != R_ACTIVE && st.round != R_UNKNOWN;
  st.round = r;
  st.roundName = name;
  st.callsign = callsign;
  if (started && screen != S_ALARM) playBeep();
  if (screen == S_HOME) dirty = true;
}

static void onUnlinked() {
  cfg.token = "";
  saveSettings();
  ESP.restart();
}

static void startRun() {
  LOG("[run] verbinde mit " + cfg.server);
  mode = M_RUN;
  WiFi.setAutoReconnect(true);
#ifdef ESP8266
  configTime(TZ_INFO, "pool.ntp.org", "time.google.com");
#else
  configTzTime(TZ_INFO, "pool.ntp.org", "time.google.com");
#endif
  psBegin({onAlarm, onRound, onUnlinked});
  backlight(cfg.light);
  lastInput = millis();
  go(S_HOME);
}

static void startAccountSetup(bool withAP) {
  LOG("[setup] warte auf Anmeldung, Einrichtungsseite ist offen");
  mode = M_SETUP_ACCOUNT;
  setupState = SS_ACCOUNT;
  portalBegin(withAP);
  dirty = true;
}

static bool connectSaved() {
  WiFi.mode(WIFI_STA);
#ifdef ESP8266
  WiFi.hostname(apName());
#else
  WiFi.setHostname(apName().c_str());
#endif
  WiFi.begin(cfg.ssid.c_str(), cfg.pass.c_str());
  uiSetup("PagerSpass", "Verbinde mit WLAN", cfg.ssid, "", "");
  uint32_t t = millis();
  while (millis() - t < 20000) {
    if (WiFi.status() == WL_CONNECTED) return true;
    delay(100);
  }
  return false;
}

// ---------- Einrichtung ----------

static void setupLoop() {
  portalLoop();

  String a, b, c;
  if (takeWifiRequest(a, b)) {
    pendingSsid = a;
    pendingPass = b;
    WiFi.disconnect();
    WiFi.begin(a.c_str(), b.c_str());
    wifiTryStart = millis();
    uiSetup("Einrichtung 1/2", "Verbinde mit WLAN", a, "", "");
  }

  if (setupState == SS_WIFI_TRY) {
    if (WiFi.status() == WL_CONNECTED) {
      cfg.ssid = pendingSsid;
      cfg.pass = pendingPass;
      saveSettings();
      setupError = "";
      if (cfg.token.length()) {
        setupState = SS_DONE;
        doneAt = millis();
        mode = M_SETUP_ACCOUNT;
      } else {
        startAccountSetup(false);
      }
      dirty = true;
    } else if (millis() - wifiTryStart > 15000) {
      WiFi.disconnect();
      setupError = WiFi.status() == WL_NO_SSID_AVAIL ? "WLAN nicht gefunden" : "Passwort falsch?";
      setupState = SS_WIFI_FAIL;
      WiFi.scanNetworks(true);
      dirty = true;
    }
  }

  Login login;
  bool tried = false;
  if (takeAccountRequest(a, b, c)) {
    showSetupAccount();
    pendingServer = a;
    login = psLogin(a, b, c);
    tried = true;
  }
  if (takeCodeRequest(a)) {
    showSetupAccount();
    login = psLogin2fa(pendingServer, pendingRequest, a);
    tried = true;
  }
  if (tried) {
    if (login.ok) {
      cfg.server = login.server.length() ? login.server : pendingServer;
      cfg.user = login.user;
      cfg.token = login.token;
      saveSettings();
      setupState = SS_DONE;
      doneAt = millis();
      playBeep();
    } else if (login.twoFactor) {
      if (login.server.length()) pendingServer = login.server;
      pendingRequest = login.request;
      setupHint = login.target;
      setupError = "";
      setupState = SS_CODE;
    } else {
      setupError = login.err;
      setupState = SS_LINK_FAIL;
    }
    dirty = true;
  }

  if (setupState == SS_DONE && millis() - doneAt > 6000) {
    portalStop();
    startRun();
    return;
  }

  if (dirty) {
    dirty = false;
    if (mode == M_SETUP_WIFI) showSetupWifi();
    else showSetupAccount();
  }

  if (buttonsRead() == B_BACK_LONG) ESP.restart();
}

// ---------- Menue ----------

static String menuValue(int i) {
  switch (i) {
    case MN_MSGS: return String(msgCount);
    case MN_VOL: return String(cfg.volume);
    case MN_TONE: return toneName(cfg.tone);
    case MN_LIGHT: return String(cfg.light);
    case MN_MUTE: return cfg.mute ? "An" : "Aus";
    default: return "";
  }
}

static void drawMenu() {
  static const char *names[MN_COUNT] = {"Nachrichten", "Lautstärke", "Alarmton", "Helligkeit", "Stumm", "Info", "WLAN ändern", "Konto trennen", "Werkseinstellungen"};
  String items[MN_COUNT], values[MN_COUNT];
  for (int i = 0; i < MN_COUNT; i++) {
    items[i] = names[i];
    values[i] = menuValue(i);
  }
  uiMenu("Menü", items, values, MN_COUNT, menuSel);
}

static void drawValue() {
  switch (editing) {
    case MN_VOL: uiValue("Lautstärke", editVal == 0 ? "Aus" : String(editVal) + " / 5", ""); break;
    case MN_TONE: uiValue("Alarmton", toneName(editVal), ""); break;
    case MN_LIGHT: uiValue("Helligkeit", String(editVal) + " / 5", ""); break;
    default: break;
  }
}

static void drawInfo() {
  String l[10];
  int bat = st.battery;
  l[0] = "Gerät: " + apName();
  l[1] = "Firmware: " FW_VERSION;
  l[2] = "WLAN: " + cfg.ssid + (st.wifi ? String(String(" (") + st.rssi + " dBm)") : String(" (getrennt)"));
  l[3] = "IP: " + WiFi.localIP().toString();
  l[4] = "Server: " + cfg.server;
  l[5] = "Konto: " + cfg.user;
  l[6] = String("PagerSpass: ") + (st.server ? "verbunden" : "nicht verbunden");
  l[7] = "Akku: " + (bat >= 0 ? String(String(bat) + " %") : String("USB"));
  l[8] = "Nachrichten: " + String(msgCount) + " (" + unreadCount() + " neu)";
  l[9] = "Laufzeit: " + String(millis() / 60000) + " min";
  infoScroll = uiInfo(l, 10, infoScroll);
}

static void askConfirm(Confirm c) {
  confirming = c;
  confirmBack = screen;
  go(S_CONFIRM);
}

static void doConfirm() {
  switch (confirming) {
    case C_DELETE:
      deleteMsg(msgIdx);
      listSel = min(listSel, max(0, msgCount - 1));
      go(S_LIST);
      break;
    case C_DELETE_ALL:
      clearMsgs();
      listSel = 0;
      go(S_LIST);
      break;
    case C_WIFI:
      cfg.ssid = "";
      cfg.pass = "";
      saveSettings();
      ESP.restart();
      break;
    case C_UNLINK:
      cfg.token = "";
      saveSettings();
      ESP.restart();
      break;
    case C_RESET:
      factoryReset();
      break;
  }
}

static void openMsg(int i) {
  msgIdx = i;
  msgScroll = 0;
  if (!msgs[i].read) {
    msgs[i].read = 1;
    saveMsgs();
  }
  go(S_MSG);
}

static void ackAlarm() {
  soundStop();
  ledBlink(false);
  psAck();
  if (!msgs[0].read) {
    msgs[0].read = 1;
    saveMsgs();
  }
  go(S_HOME);
}

static void handleButton(Btn b) {
  switch (screen) {
    case S_ALARM:
      ackAlarm();
      break;

    case S_HOME:
      if (b == B_OK) { menuSel = 0; go(S_MENU); }
      else if (b == B_UP || b == B_DOWN) { listSel = 0; go(S_LIST); }
      break;

    case S_MENU:
      if (b == B_UP) menuSel = (menuSel + MN_COUNT - 1) % MN_COUNT;
      else if (b == B_DOWN) menuSel = (menuSel + 1) % MN_COUNT;
      else if (b == B_BACK) { go(S_HOME); break; }
      else if (b == B_OK) {
        switch (menuSel) {
          case MN_MSGS: listSel = 0; go(S_LIST); break;
          case MN_VOL: editing = MN_VOL; editVal = cfg.volume; go(S_VALUE); break;
          case MN_TONE: editing = MN_TONE; editVal = cfg.tone; go(S_VALUE); break;
          case MN_LIGHT: editing = MN_LIGHT; editVal = cfg.light; go(S_VALUE); break;
          case MN_MUTE: cfg.mute = !cfg.mute; saveSettings(); break;
          case MN_INFO: infoScroll = 0; go(S_INFO); break;
          case MN_WIFI: askConfirm(C_WIFI); break;
          case MN_UNLINK: askConfirm(C_UNLINK); break;
          case MN_RESET: askConfirm(C_RESET); break;
        }
      }
      dirty = true;
      break;

    case S_LIST:
      if (b == B_BACK) go(S_HOME);
      else if (!msgCount) break;
      else if (b == B_UP) listSel = (listSel + msgCount - 1) % msgCount;
      else if (b == B_DOWN) listSel = (listSel + 1) % msgCount;
      else if (b == B_OK) openMsg(listSel);
      else if (b == B_OK_LONG) askConfirm(C_DELETE_ALL);
      dirty = true;
      break;

    case S_MSG:
      if (b == B_BACK) { listSel = msgIdx; go(S_LIST); }
      else if (b == B_OK || b == B_OK_LONG) askConfirm(C_DELETE);
      else if (b == B_DOWN) {
        if (msgScroll + 5 < msgLines) msgScroll++;
        else if (msgIdx + 1 < msgCount) openMsg(msgIdx + 1);
      } else if (b == B_UP) {
        if (msgScroll > 0) msgScroll--;
        else if (msgIdx > 0) openMsg(msgIdx - 1);
      }
      dirty = true;
      break;

    case S_VALUE: {
      int maxV = editing == MN_TONE ? toneCount() - 1 : 5;
      int minV = editing == MN_LIGHT ? 1 : 0;
      if (b == B_UP || b == B_DOWN) {
        editVal += b == B_UP ? 1 : -1;
        if (editing == MN_TONE) editVal = (editVal + toneCount()) % toneCount();
        else editVal = constrain(editVal, minV, maxV);
        if (editing == MN_VOL) { uint8_t old = cfg.volume; cfg.volume = editVal; soundStop(); playBeep(); cfg.volume = old; }
        if (editing == MN_TONE) { soundStop(); playAlarm(editVal, 1, false); }
        if (editing == MN_LIGHT) backlight(editVal);
      } else if (b == B_OK) {
        if (editing == MN_VOL) cfg.volume = editVal;
        if (editing == MN_TONE) cfg.tone = editVal;
        if (editing == MN_LIGHT) cfg.light = editVal;
        saveSettings();
        soundStop();
        go(S_MENU);
      } else if (b == B_BACK) {
        soundStop();
        backlight(cfg.light);
        go(S_MENU);
      }
      dirty = true;
      break;
    }

    case S_CONFIRM:
      if (b == B_OK) doConfirm();
      else if (b == B_BACK) go(confirmBack);
      break;

    case S_INFO:
      if (b == B_BACK || b == B_OK) go(S_MENU);
      else if (b == B_DOWN) { infoScroll++; dirty = true; }
      else if (b == B_UP && infoScroll > 0) { infoScroll--; dirty = true; }
      break;
  }
}

static void draw() {
  switch (screen) {
    case S_HOME: uiHome(); break;
    case S_MENU: drawMenu(); break;
    case S_LIST: uiMsgList(listSel); break;
    case S_MSG:
    case S_ALARM: msgLines = uiMsg(msgIdx, msgScroll); break;
    case S_VALUE: drawValue(); break;
    case S_CONFIRM:
      uiConfirm(confirming == C_DELETE ? "Nachricht löschen?" :
                confirming == C_DELETE_ALL ? "Alle Nachrichten löschen?" :
                confirming == C_WIFI ? "WLAN-Daten löschen und neu einrichten?" :
                confirming == C_UNLINK ? "Pager von deinem PagerSpass Konto trennen?" :
                "Alles auf Werkseinstellungen zurücksetzen?");
      break;
    case S_INFO: drawInfo(); break;
  }
}

static void runLoop() {
  psLoop();
  uint32_t now = millis();

  Btn b = buttonsRead();
  if (b != B_NONE) {
    bool wasDark = !lightOn;
    wake();
    if (!wasDark || screen == S_ALARM) {
      playClick();
      handleButton(b);
    }
  }

  if (screen == S_ALARM && alarmStart && now - alarmStart > ALARM_SECONDS * 1000UL) {
    soundStop();
    alarmStart = 0;
  }

  bool ringing = screen == S_ALARM && alarmStart;
  if (lightOn && !ringing && now - lastInput > LIGHT_SECONDS * 1000UL) {
    lightOn = false;
    backlight(0);
    if (screen != S_HOME && screen != S_ALARM) go(S_HOME);
  }

  if (now - lastTick > 1000) {
    lastTick = now;
    bool w = WiFi.status() == WL_CONNECTED;
    bool s = psConnected();
    int bat = readBattery();
    if (w != st.wifi || s != st.server || abs(bat - st.battery) > 1) dirty |= screen == S_HOME;
    st.wifi = w;
    st.server = s;
    st.rssi = WiFi.RSSI();
    st.battery = bat;
    if (screen == S_HOME) {
      static int lastMin = -1;
      int m = (time(nullptr) / 60) % 60;
      if (m != lastMin) { lastMin = m; dirty = true; }
    }
  }

  if (dirty) {
    dirty = false;
    draw();
  }
}

void setup() {
#ifndef ESP8266
  Serial.begin(115200);
#endif
  LOG("\n[boot] PagerSpass Pager " FW_VERSION);
  storeBegin();
  buttonsBegin();
  soundBegin();
  displayBegin();
  LOG("[boot] Display gestartet");
  uiWelcome();
  backlight(4);
  playBeep();

  uint32_t t = millis();
  while (millis() - t < 2500) {
    soundLoop();
    delay(5);
  }

  if (buttonHeld(PIN_BTN_UP) && buttonHeld(PIN_BTN_DOWN)) {
    uiSetup("Zurücksetzen", "Beide Tasten 5 Sekunden halten um alles zu löschen.", "", "", "");
    t = millis();
    while (buttonHeld(PIN_BTN_UP) && buttonHeld(PIN_BTN_DOWN)) {
      if (millis() - t > 5000) {
        uiSetup("Zurücksetzen", "Werkseinstellungen...", "", "", "");
        factoryReset();
      }
      delay(20);
    }
  }

  LOG("[wifi] verbinde mit " + cfg.ssid);
  if (cfg.ssid.length() && connectSaved()) {
    LOG("[wifi] verbunden, IP " + WiFi.localIP().toString());
    if (cfg.token.length()) startRun();
    else startAccountSetup(false);
    return;
  }

  LOG("[wifi] kein WLAN, starte Einrichtung " + apName());
  mode = M_SETUP_WIFI;
  setupState = cfg.ssid.length() ? SS_WIFI_FAIL : SS_WIFI;
  if (cfg.ssid.length()) setupError = "Gespeichertes WLAN \"" + cfg.ssid + "\" nicht erreichbar";
  portalBegin(true);
  dirty = true;
}

void loop() {
  soundLoop();
  if (mode == M_RUN) runLoop();
  else setupLoop();
  delay(2);
}

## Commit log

2026-09-25 Firmware und Testserver
2026-09-25 Gehaeuse (OpenSCAD + STL)
    [pager.scad, pager_back.stl, pager_buttons.stl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]
2026-09-25 Doku und Anleitung
2026-09-26 Simulator: offizielles ESP32-C3 Board, serielle Ausgabe
2026-09-26 Umbau auf WeMos D1 Mini (ESP8266) und 1.9 Zoll Display, groessere Schrift
2026-09-26 Gehaeuse fuer D1 Mini, 1.9 Zoll Display und Taster 6x6x4.3
    [pager.scad, pager_back.stl, pager_buttons.stl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]
2026-09-26 Schaltplan, Teileliste und Anleitung angepasst
